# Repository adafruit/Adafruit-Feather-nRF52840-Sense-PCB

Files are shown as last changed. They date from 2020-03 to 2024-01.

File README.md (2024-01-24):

## Adafruit Feather nRF52840 Sense PCB

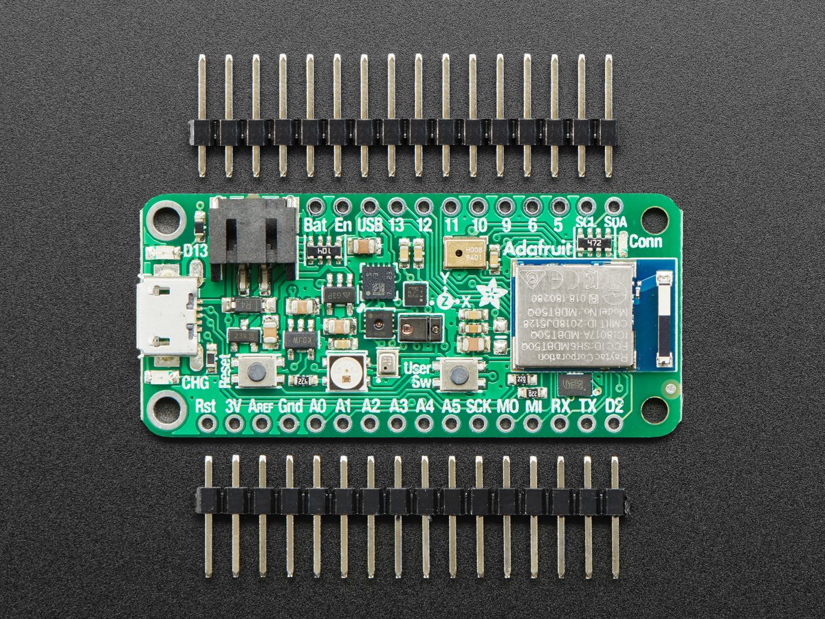
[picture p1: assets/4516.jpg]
<a href="http://www.adafruit.com/products/4516"><br/>
Click here to purchase one from the Adafruit shop</a>

PCB files for the Adafruit Feather nRF52840 Sense. 

Format is EagleCAD schematic and board layout
* https://www.adafruit.com/product/4516

### Description

The Adafruit Feather Bluefruit Sense takes our popular Feather nRF52840 Express and adds a smorgasbord of sensors to make a great wireless sensor platform. This Feather microcontroller comes with Bluetooth Low Energy and native USB support featuring the nRF52840!  This Feather is an 'all-in-one' Arduino-compatible + Bluetooth Low Energy with built in USB plus battery charging. With native USB it works great with CircuitPython, too.

Like the Feather nRF52840, this chip comes with Arduino IDE support - you can program the nRF52840 chip directly to take full advantage of the Cortex-M4 processor, and then calling into the Nordic SoftDevice radio stack when you need to communicate over BLE. Since the underlying API and peripherals are the same for the '832 and '840, you can supercharge your older nRF52832 projects with the same exact code, with a single recompile!

This Feather is also a BLE-friendly CircuitPython board! CircuitPython works best with disk drive access, and this is the only BLE-plus-USB-native chip that has the memory to handle running a little Python interpreter. The massive RAM and speedy Cortex M4F chip make this a good match. Make centrals or peripherals with the ease of CircuitPython.

A chorus of supporting sensors surround the module so you can do all sorts of environmental and motion sensing:

* ST Micro series 9-DoF motion - LSM6DS33 Accel/Gyro + LIS3MDL magnetometer
* APDS9960 Proximity, Light, Color, and Gesture Sensor
* PDM Microphone sound sensor
* SHT Humidity
* BMP280 temperature and barometric pressure/altitude

Features:

* ARM Cortex M4F (with HW floating point acceleration) running at 64MHz
* 1MB flash and 256KB SRAM
* Native Open Source USB stack - pre-programmed with UF2 bootloader
* Bluetooth Low Energy compatible 2.4GHz radio (Details available in the nRF52840 product specification)
* FCC / IC / TELEC certified module
* Up to +8dBm output power
* 21 GPIO, 6 x 12-bit ADC pins, up to 12 PWM outputs (3 PWM modules with 4 outputs each)
* Pin #13 red LED for general purpose blinking, Blue LED for general purpose connection status, NeoPixel for colorful feedback
* Power/enable pin
* Measures 2.0" x 0.9" x 0.28" (51mm x 23mm x 7.2mm) without headers soldered in
* Light as a (large?) feather - 6 grams
* 4 mounting holes
* Reset button
* SWD debug pads on bottom of PCB
* Works out of the box with all of our Adafruit FeatherWings! (Even the UART-using ones like the GPS FeatherWing)

As of January 10, 2024 - We have replaced the discontinued LSM6DS33 with an LSM6DS3TR-C 6 DoF sensor. The performance is improved however new firmware libraries will need to be used in order to read the accelerometer and gyroscope.

### License

Adafruit invests time and resources providing this open source design, please support Adafruit and open-source hardware by purchasing products from [Adafruit](https://www.adafruit.com)!

Designed by Limor Fried/Ladyada for Adafruit Industries.

Creative Commons Attribution/Share-Alike, all text above must be included in any redistribution. 
See license.txt for additional details.

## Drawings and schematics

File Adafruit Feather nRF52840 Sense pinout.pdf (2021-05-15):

# Adafruit Feather nRF52840 Sense

## https://www.adafruit.com/product/4516

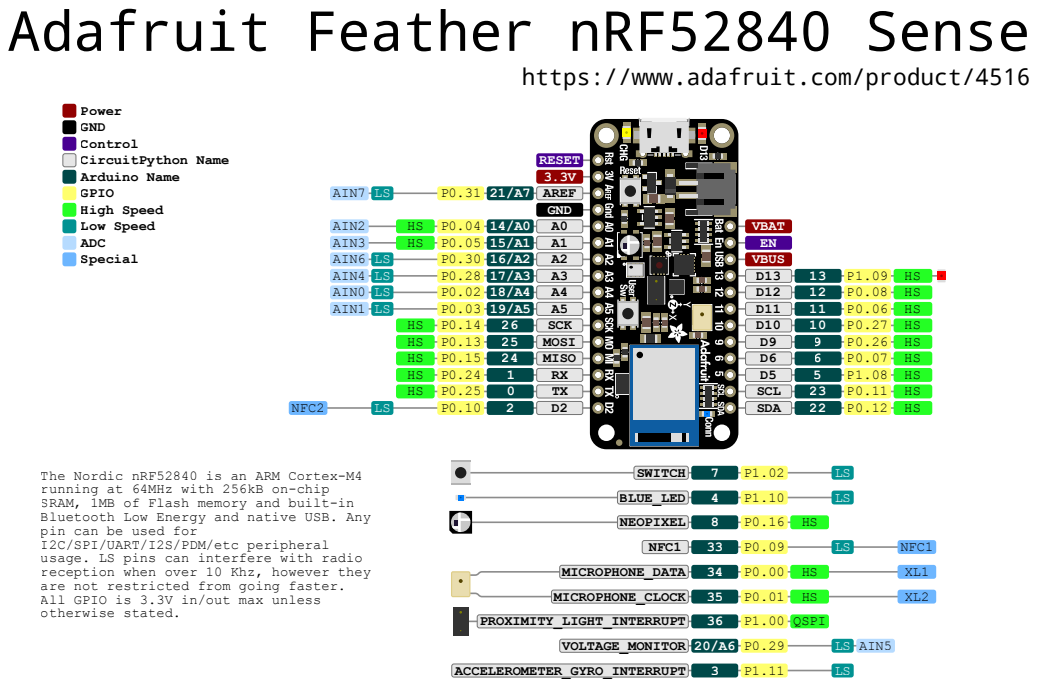
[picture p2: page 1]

The Nordic nRF52840 is an ARM Cortex-M4
running at 64MHz with 256kB on-chip
SRAM, 1MB of Flash memory and built-in
Bluetooth Low Energy and native USB. Any
pin can be used for
I2C/SPI/UART/I2S/PDM/etc peripheral
usage. LS pins can interfere with radio
reception when over 10 Khz, however they
are not restricted from going faster.
All GPIO is 3.3V in/out max unless
otherwise stated.

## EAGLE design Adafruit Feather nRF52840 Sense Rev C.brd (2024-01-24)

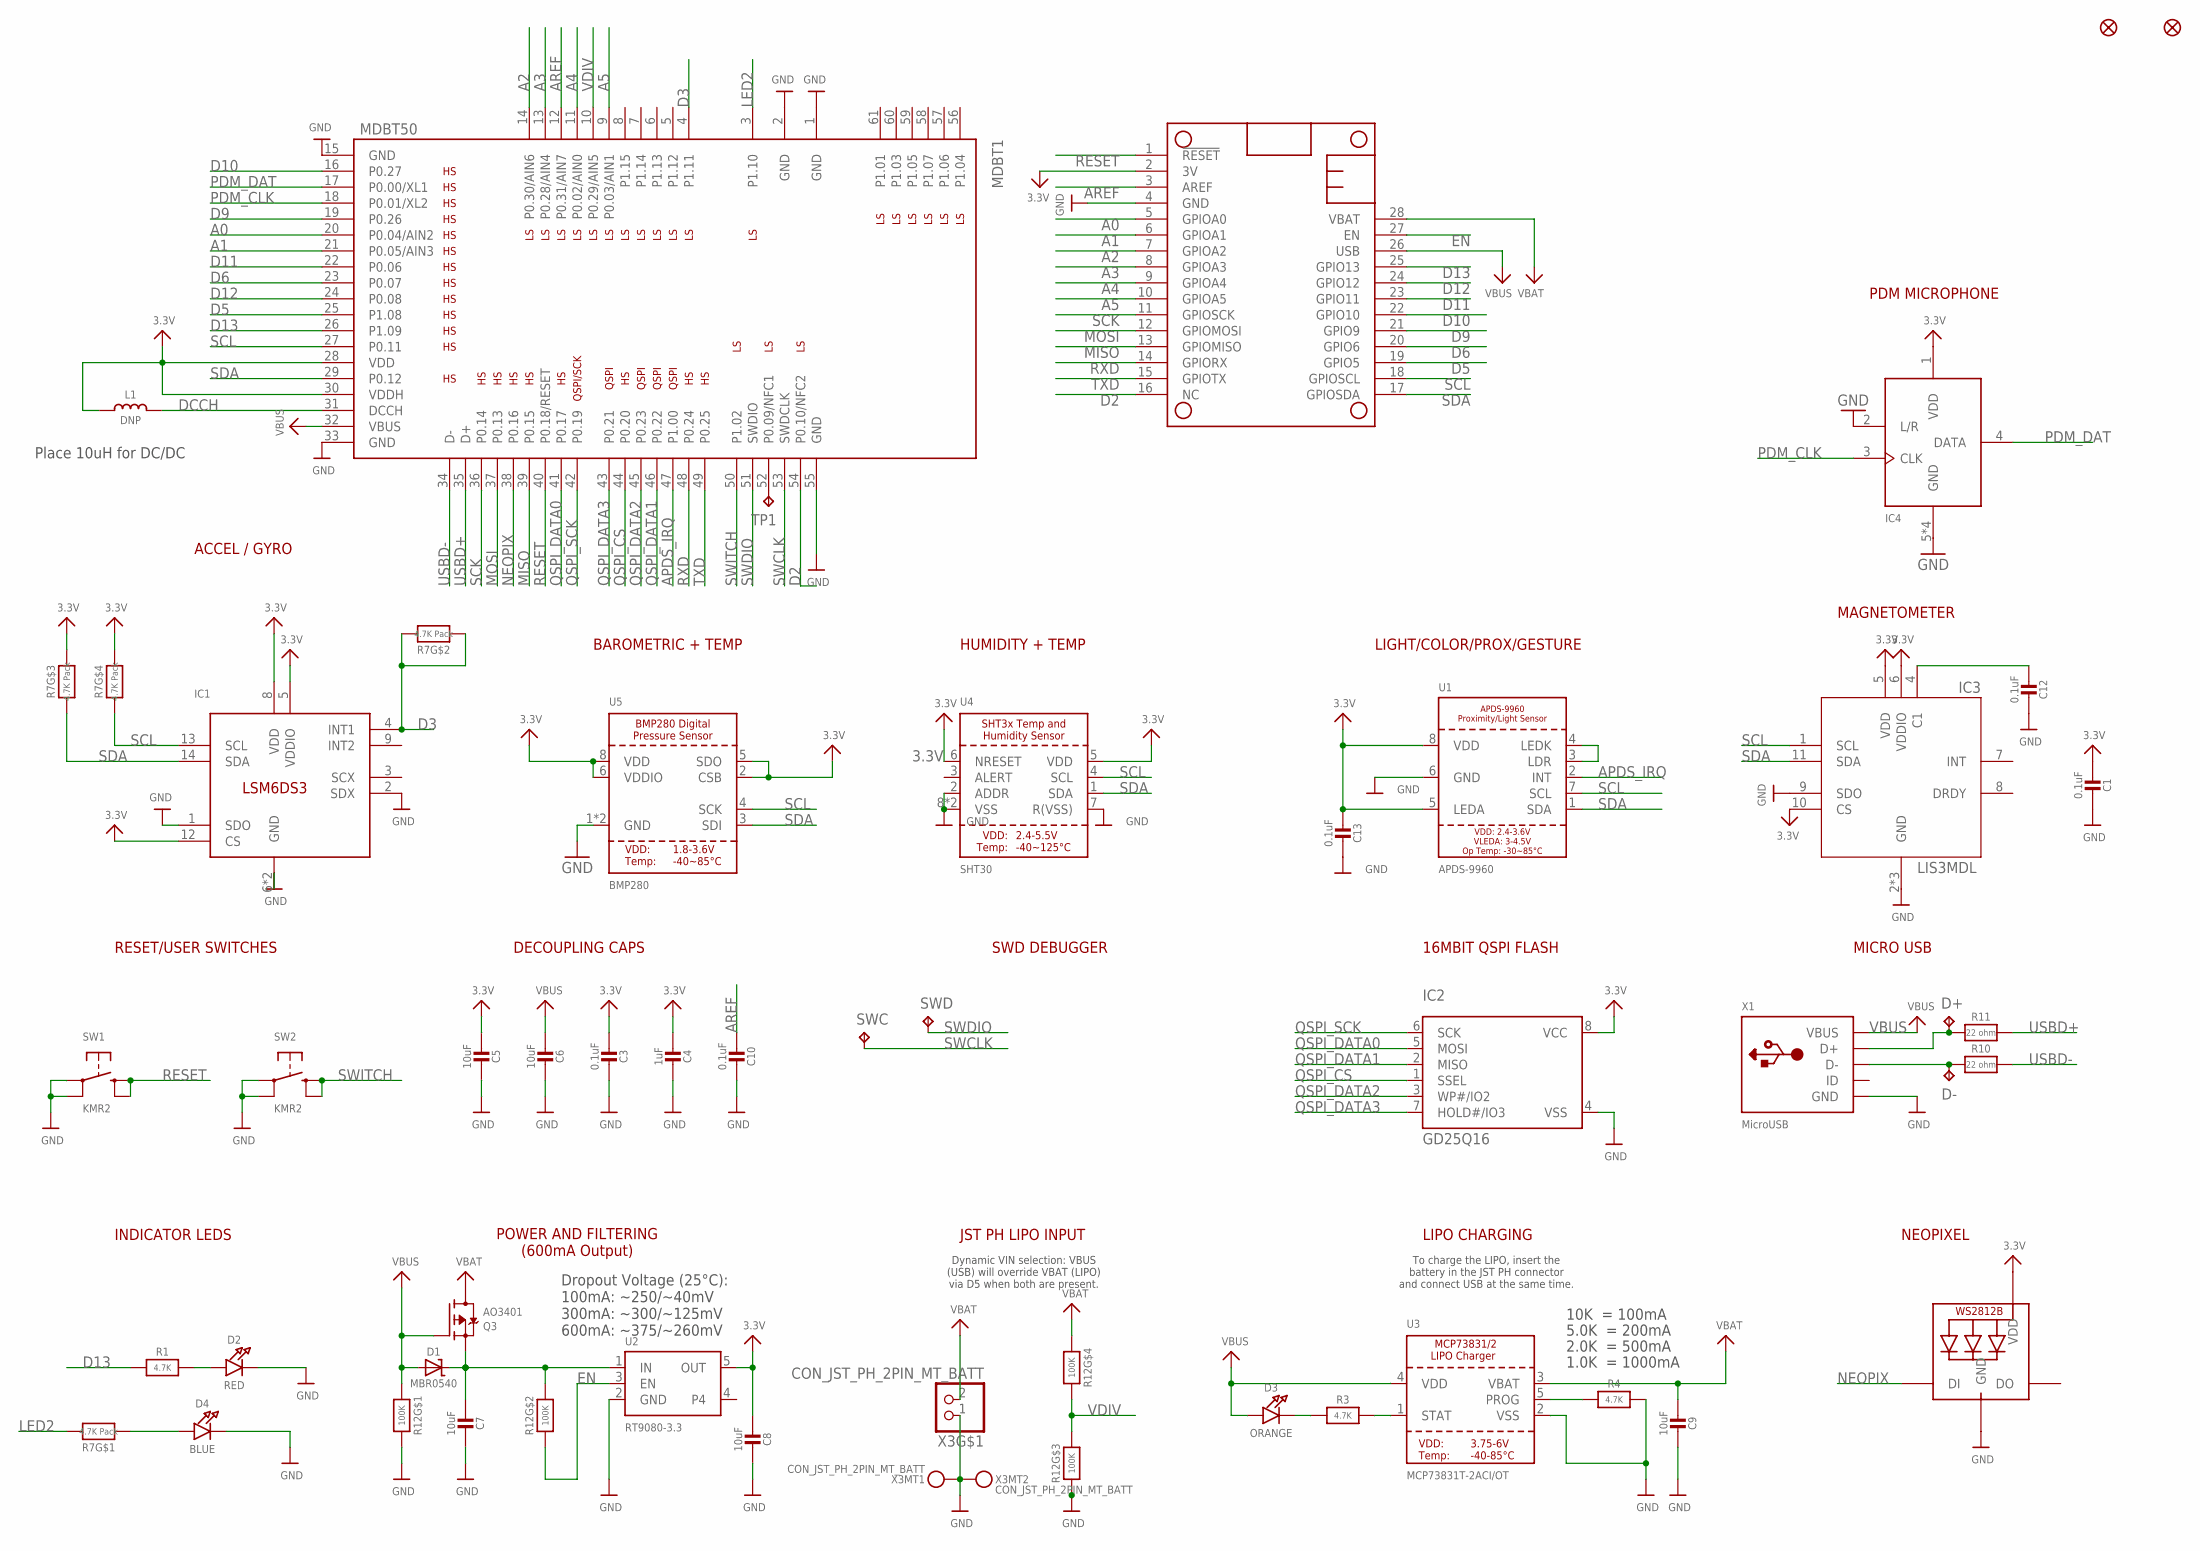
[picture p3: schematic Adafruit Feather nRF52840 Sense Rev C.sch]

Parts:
C1, C3, C10, C12, C13: 0.1uF; 0603-NO
C4: 1uF; 0603-NO
C5, C6, C7, C8, C9: 10uF; 0805-NO
D1: MBR0540; SOD-123
D2: RED; CHIPLED_0603_NOOUTLINE
D3: ORANGE; CHIPLED_0603_NOOUTLINE
D4: BLUE; CHIPLED_0603_NOOUTLINE
D+: TPTP10R; TP10R
D-: TPTP10R; TP10R
FID1, FID2: FIDUCIAL_1MM
IC1: LSM6DS3; LGA-14L
IC2: GD25Q16; USON8
IC3: LIS3MDL; LGA12_2X2MM
IC4: MIC_PDM; SPK0415HM4H
L1: DNP; _0805MP
LED1: WS2812B_3535FULL; LED3535_FULLPADS
MDBT1: MDBT50
MS1: FEATHERWING_NODIM
Q3: AO3401; SOT23-R
R1, R3, R4: 4.7K; 0603-NO
R7: 4.7K Pack; RESPACK_4X0603
R10, R11: 22 ohm; 0603-NO
R12: 100K; RESPACK_4X0603
SW1, SW2: KMR2; BTN_RKB2_4.6X2.8
SWC: TPTP12R; TP12R
SWD: TPTP12R; TP12R
TP1: TPTP10R; TP10R
U1: APDS-9960
U2: RT9080-3.3; SOT23-5; JLC_ROTATION 0
U3: MCP73831T-2ACI/OT; SOT23-5
U4: SHT30; SHT3X
U5: BMP280
X1: MicroUSB; 4UCONN_20329_V2
X3: CON_JST_PH_2PIN_MT_BATT; JSTPH2_BATT

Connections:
3.3V: C1.2, C3.2, C4.2, C5.2, C8.2, C13.2, IC1.5 (VDDIO), IC1.8 (VDD), IC1.12 (CS), IC2.8 (VCC), IC3.5 (VDD), IC3.6 (VDDIO), IC3.10 (CS), IC4.1 (VDD), L1.1, LED1.2 (VDD), MDBT1.28 (VDD), MDBT1.30 (VDDH), MS1.2 (3V), R7.5 (2), R7.6 (2), U1.5 (LEDA), U1.8 (VDD), U2.5 (OUT), U4.5 (VDD), U4.6 (NRESET), U5.2 (CSB), U5.5 (SDO), U5.6 (VDDIO), U5.8 (VDD)
A0: MDBT1.20 (P0.04/AIN2), MS1.5 (GPIOA0)
A1: MDBT1.21 (P0.05/AIN3), MS1.6 (GPIOA1)
A2: MDBT1.14 (P0.30/AIN6), MS1.7 (GPIOA2)
A3: MDBT1.13 (P0.28/AIN4), MS1.8 (GPIOA3)
A4: MDBT1.11 (P0.02/AIN0), MS1.9 (GPIOA4)
A5: MDBT1.9 (P0.03/AIN1), MS1.10 (GPIOA5)
APDS_IRQ: MDBT1.47 (P1.00), U1.2 (INT)
AREF: C10.2, MDBT1.12 (P0.31/AIN7), MS1.3 (AREF)
CAP1: C12.2, IC3.4 (C1)
D2: MDBT1.54 (P0.10/NFC2), MS1.16 (NC)
D3: IC1.4 (INT1), MDBT1.4 (P1.11), R7.2 (1), R7.7 (2)
D5: MDBT1.25 (P1.08), MS1.19 (GPIO5)
D6: MDBT1.23 (P0.07), MS1.20 (GPIO6)
D9: MDBT1.19 (P0.26), MS1.21 (GPIO9)
D10: MDBT1.16 (P0.27), MS1.22 (GPIO10)
D11: MDBT1.22 (P0.06), MS1.23 (GPIO11)
D12: MDBT1.24 (P0.08), MS1.24 (GPIO12)
D13: MDBT1.26 (P1.09), MS1.25 (GPIO13), R1.1
D+: D+.TP, R11.1, X1.D+
D-: D-.TP, R10.1, X1.D-
DCCH: L1.2, MDBT1.31 (DCCH)
EN: MS1.27 (EN), R12.2 (1), U2.3 (EN)
GND: C1.1, C3.1, C4.1, C5.1, C6.1, C7.1, C8.1, C9.1, C10.1, C12.1, C13.1, D2.C, D4.C, IC1.1 (SDO), IC1.2 (SDX), IC1.6 (GND), IC1.7 (GND), IC2.4 (VSS), IC3.2 (GND), IC3.3 (GND), IC3.9 (SDO), IC3.12 (GND), IC4.2 (L/R), IC4.5 (GND), IC4.6 (GND), IC4.7 (GND), IC4.8 (GND), LED1.4 (GND), MDBT1.1 (GND), MDBT1.2 (GND), MDBT1.15 (GND), MDBT1.33 (GND), MDBT1.55 (GND), MS1.4 (GND), R4.2, R12.3 (1), R12.8 (2), SW1.A, SW1.A' (P1), SW2.A, SW2.A' (P1), U1.6 (GND), U2.2 (GND), U3.2 (VSS), U4.2 (ADDR), U4.7 (R(VSS)), U4.8 (VSS), U4.THERMAL (VSS), U5.1 (GND), U5.7 (GND), X1.BASE@1 (GND), X1.BASE@2 (GND), X1.GND, X1.SPRT@1 (GND), X1.SPRT@2 (GND), X1.SPRT@3 (GND), X1.SPRT@4 (GND), X3.1, X3.NC1, X3.NC2
LED2: MDBT1.3 (P1.10), R7.8 (2)
MISO: MDBT1.39 (P0.15), MS1.13 (GPIOMISO)
MOSI: MDBT1.37 (P0.13), MS1.12 (GPIOMOSI)
unnamed: D3.C, R3.1
unnamed: U1.3 (LDR), U1.4 (LEDK)
unnamed: D4.A, R7.1
unnamed: D2.A, R1.2
unnamed: R3.2, U3.1 (STAT)
unnamed: R4.1, U3.5 (PROG)
NEOPIX: LED1.1 (DI), MDBT1.38 (P0.16)
NFC2: MDBT1.52 (P0.09/NFC1), TP1.TP
PDM_CLK: IC4.3 (CLK), MDBT1.18 (P0.01/XL2)
PDM_DAT: IC4.4 (DATA), MDBT1.17 (P0.00/XL1)
QSPI_CS: IC2.1 (SSEL), MDBT1.44 (P0.20)
QSPI_DATA0: IC2.5 (MOSI), MDBT1.41 (P0.17)
QSPI_DATA1: IC2.2 (MISO), MDBT1.46 (P0.22)
QSPI_DATA2: IC2.3 (WP#/IO2), MDBT1.45 (P0.23)
QSPI_DATA3: IC2.7 (HOLD#/IO3), MDBT1.43 (P0.21)
QSPI_SCK: IC2.6 (SCK), MDBT1.42 (P0.19)
RESET: MDBT1.40 (P0.18/RESET), MS1.1 (!RESET), SW1.B (S), SW1.B' (S1)
RXD: MDBT1.48 (P0.24), MS1.14 (GPIORX)
SCK: MDBT1.36 (P0.14), MS1.11 (GPIOSCK)
SCL: IC1.13 (SCL), IC3.1 (SCL), MDBT1.27 (P0.11), MS1.18 (GPIOSCL), R7.4 (1), U1.7 (SCL), U4.4 (SCL), U5.4 (SCK)
SDA: IC1.14 (SDA), IC3.11 (SDA), MDBT1.29 (P0.12), MS1.17 (GPIOSDA), R7.3 (1), U1.1 (SDA), U4.1 (SDA), U5.3 (SDI)
SWCLK: MDBT1.53 (SWDCLK), SWC.TP
SWDIO: MDBT1.51 (SWDIO), SWD.TP
SWITCH: MDBT1.50 (P1.02), SW2.B (S), SW2.B' (S1)
TXD: MDBT1.49 (P0.25), MS1.15 (GPIOTX)
USBD+: MDBT1.35 (D+), R11.2
USBD-: MDBT1.34 (D-), R10.2
VBAT: C9.2, MS1.28 (VBAT), Q3.3 (D), R12.4 (1), U3.3 (VBAT), X3.2
VBUS: C6.2, D1.A, D3.A, MDBT1.32 (VBUS), MS1.26 (USB), Q3.1 (G), R12.1, U3.4 (VDD), X1.VBUS
VDIV: MDBT1.10 (P0.29/AIN5), R12.5 (2), R12.6 (2)
VHI: C7.2, D1.C, Q3.2 (S), R12.7 (2), U2.1 (IN)

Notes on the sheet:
10K = 100mA
5.0K = 200mA
2.0K = 500mA
1.0K = 1000mA
LIPO CHARGING
To charge the LIPO, insert the battery in the JST PH connector and connect USB at the same time.
POWER AND FILTERING (600mA Output)
JST PH LIPO INPUT
Dynamic VIN selection: VBUS (USB) will override VBAT (LIPO) via D5 when both are present.
Dropout Voltage (25°C): 100mA: ~250/~40mV 300mA: ~300/~125mV 600mA: ~375/~260mV
INDICATOR LEDS
RESET/USER SWITCHES
DECOUPLING CAPS
SWD DEBUGGER
16MBIT QSPI FLASH
MICRO USB
NEOPIXEL
Place 10uH for DC/DC
ACCEL / GYRO
BAROMETRIC + TEMP
HUMIDITY + TEMP
LIGHT/COLOR/PROX/GESTURE
MAGNETOMETER
PDM MICROPHONE

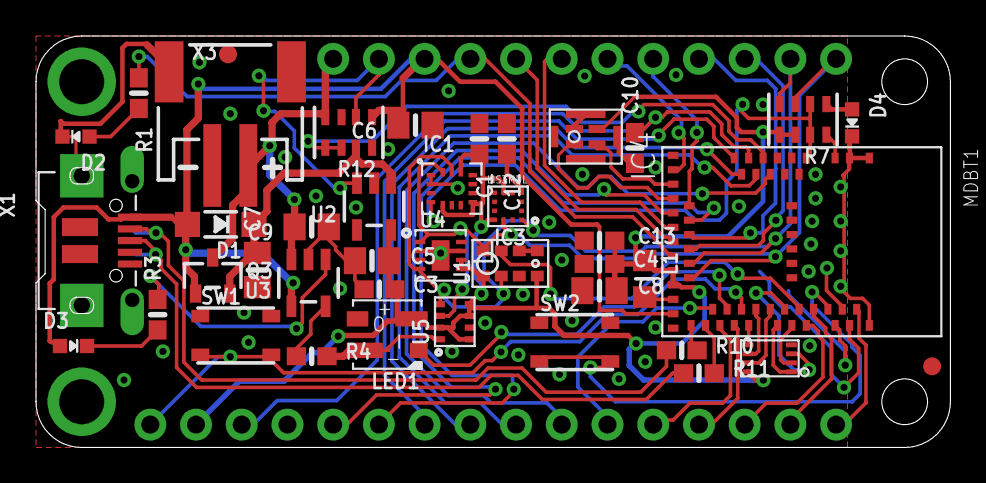
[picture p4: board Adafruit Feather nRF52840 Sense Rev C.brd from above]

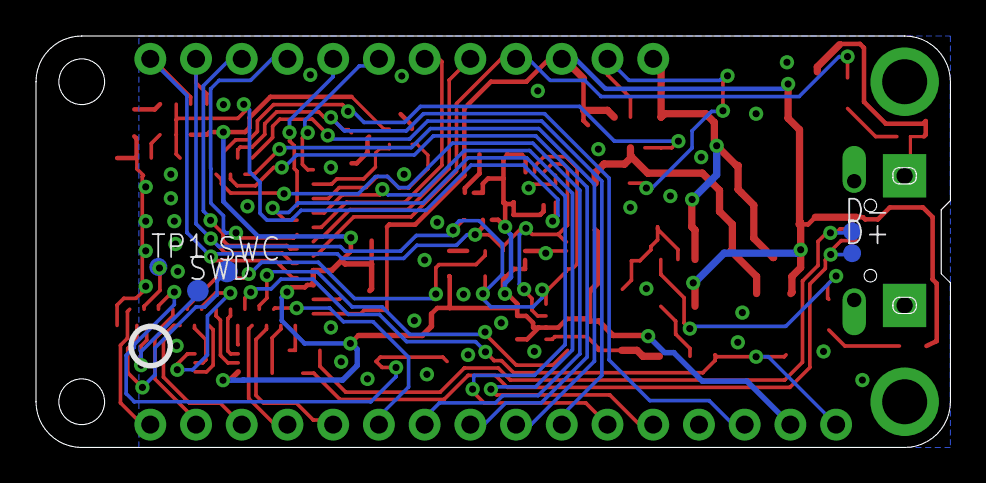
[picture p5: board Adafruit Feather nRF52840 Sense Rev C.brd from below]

Board: 2 copper layers, 50.8 x 22.9 mm, 50 parts (7 on the bottom side), 58 nets.

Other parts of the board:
U$10: PCBFEAT-REV-056
U$14: FEATHERSENSE_TOP
U$75: FEATHERSENSE_BOT

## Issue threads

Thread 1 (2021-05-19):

Feature Request: add a cuttable solder jumper for neopixel power

alexwhittemore, 2021-05-19:
I hadn't thought about this before, but I'm probably not the only one who'd benefit: this board is actually AWESOME for low power work right out of the box, since all the on board sensors stay off in low-power mode until you initialize them, and as of CircuitPython 6+, the nRF goes into a low power mode anytime you time.wait(), and of course you have even more flexibility in other frameworks.

The big limiter of coin cell or long-duration LiPo operation is that the neopixel, even unlit, drasw 500-1000uA quiescent current. It'd be awesome to have a cuttable solder jumper to disable its power totally, but as it stands, the power pad is in the middle of the 3.3V routing so there aren't any traces to cut that don't also cut power to a bunch of other things.

I'd happily make a modification and submit a PR, but only if you're cool with a minor board rev next production run. I do think it's practical without moving any components.

ladyada, 2021-05-19:
i hvae to revise the PCB anyways because the IMU is EOL - will add then

alexwhittemore, 2021-05-19:
Killer, thanks!

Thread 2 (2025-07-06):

Oscillator xtal type? (internal or external)

abcd-ca, 2025-07-06:
Hello,

Would you please confirm that the Feather nRF52840 Sense board has no external oscillator and that the internal, RC one should be used instead? Looking at [XL1/XL2 in the schematic](https://learn.adafruit.com/assets/127209), I'm unclear but testing so far, my firmware seems to get further along when I specify an internal, RC oscillator rather than external xtal.

Is it true that the external oscillator is not populated? it looks like that's true because XL1/XL2 are connected to the microphone.

Thanks!

dhalbert, 2025-07-06:
The Feather nRF52840 Feather Sense does not have an LF crystal , and uses those inputs for the microphone instead. There _is_ a 64 MHz crystal inside the nRF52840 module. A 64 MHz crystal is required for the accurate timing neededto do BLE at all. So there is a crystal controlled HF clock, but not an LF clock.

There are spare pins on the module, but they are specified by Nordic to be "low speed". They are not inherently low speed but running them at high speed may interfere with the radio.

The plain Feather nRF52840 _does_ have an LF 32 kHz crystal.

abcd-ca, 2025-07-06:
Thank you, that's helpful. So I've found that my Rust firmware gets a lot further if I specify the internal LF clock rather than external, which is what I think you'd recommend based on your reply. Specifying the LF clock source is required by both the RTOS (Embassy) and by the NRF SoftDevice config. For the latter, I have,

```rust
 clock: Some(raw::nrf_clock_lf_cfg_t {
            // Use internal RC oscillator to match embassy config
            source: raw::NRF_CLOCK_LF_SRC_RC as u8,
            // RC oscillator calibration interval (16 = 4 seconds)
            rc_ctiv: 16,
            // Temperature calibration interval (2 = 0.5 seconds)
            rc_temp_ctiv: 2,
            // RC oscillator is less accurate than crystal
            accuracy: raw::NRF_CLOCK_LF_ACCURACY_250_PPM as u8,
        }),
```

Advertising does work when I use those settings above. I'm using the iOS nRF Connect app which is listing my peripheral but when I tap it to connect, it hangs on "connecting" and in my peripheral's output, it doesn't return an error or success message from the connection attempt. This `await` doesn't resolve:

```rust
let connection_result = peripheral::advertise_connectable(
            sd,
            peripheral::ConnectableAdvertisement::ScannableUndirected {
                adv_data,
                scan_data,
            },
            &adv_config,
        )
        .await;
```

I'm trying to figure out if this is at all a timer/clock interrupt issue or something else. I don't have anything else connected to my Feather at this point.

dhalbert, 2025-07-06:
> if I specify the internal LF clock rather than external

Right, this is necessary in this case. I am completely unfamiliar with the Rust code you're using, but you may need to provide some callback for a connection request or similar. You could try running some other code like a Nordic UART example in CircuitPython or ArduinoBLE to see how the app reacts. See  https://github.com/adafruit/Adafruit_CircuitPython_BLE/blob/main/examples/ble_uart_echo_test.py or https://learn.adafruit.com/bluefruit-nrf52-feather-learning-guide.

Issues for this repo are meant to be about the board. For more technical support on your BLE questions, you could ask in our discord, https://adafru.it/discord, or https://forums.adafruit.com. But I don't know anyone in either of those places who is familiar with the RTOS or code you're using. Nevertheless, your guess about the LF clock is correct.

Closed 2025-07-06.

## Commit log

2020-03-11 Adding board files.
    [Adafruit Feather nRF52840 Sense.brd, Adafruit Feather nRF52840 Sense.sch]
2021-05-15 Add pin reference PDF
2024-01-24 adding rev C
    [Adafruit Feather nRF52840 Sense Rev C.brd, Adafruit Feather nRF52840 Sense Rev C.sch]

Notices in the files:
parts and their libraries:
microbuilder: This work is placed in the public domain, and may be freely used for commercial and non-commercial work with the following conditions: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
